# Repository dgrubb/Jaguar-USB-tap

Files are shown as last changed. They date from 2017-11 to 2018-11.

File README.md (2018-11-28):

# Jaguar USB Tap

Atari Jaguar logo

The [controller](https://atariage.com/controller_page.html?ControllerID=21&SystemID=JAGUAR) for the [Atari Jaguar](https://en.wikipedia.org/wiki/Atari_Jaguar) game console is a strange beast and doesn't map well to modern controllers (in large part due to the numeric keypad). This makes emulating games on a PC with off-the-shelf controllers, which usually mimic PlayStation or XBox layouts, somewhat cumbersome. One possible solution is to create a device which can convert the Jaguar controller's pinout and signals to a USB HID device.

## Hardware

The hardware was developed using the open-source schematic and PCB design tool [KiCad](http://kicad-pcb.org/). It sports an [STM32F070](http://www.st.com/en/microcontrollers/stm32f070cb.html) ARM Cortex M0 micro-controller which handles input from the Jaguar gamepad and generate appropriate USB HID signalling.

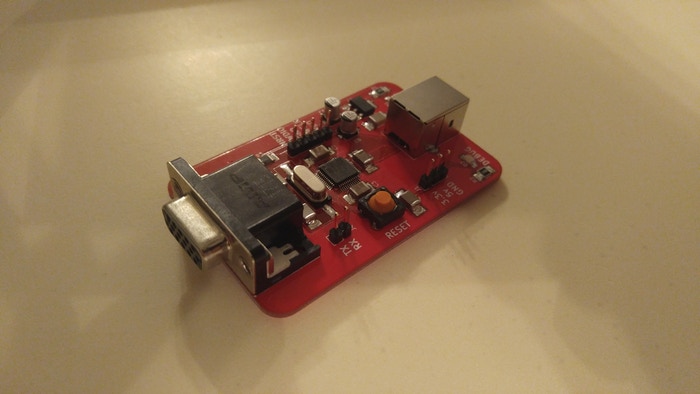
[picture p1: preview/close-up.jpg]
Assembled Jaguar USB Tap


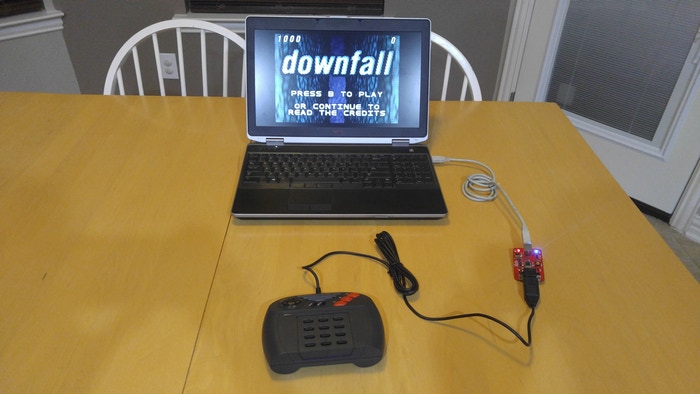
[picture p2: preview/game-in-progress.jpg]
Jaguar USB Tap


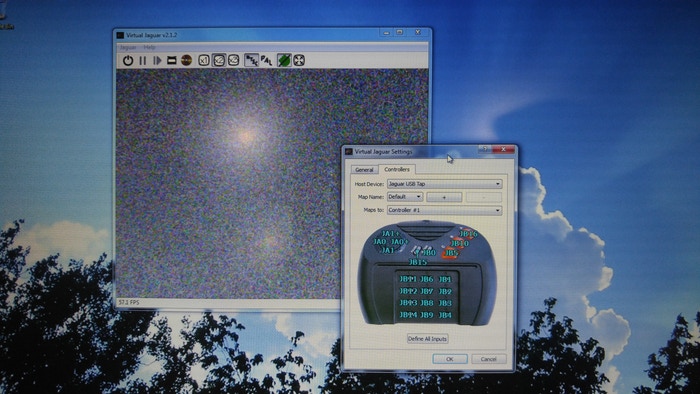
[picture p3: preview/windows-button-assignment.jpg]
Typical use case


## Accessibility

Even though the design uses entirely surface-mount (SMD) components, with the exception of connectors, I selected components with relatively large footprints such as 1812 for non-polarised capacitors. Larger components resulted in the PCB being bigger than it needs to be, but I feel this to be an acceptable trade-off to ensure that the design is accessible as they require less skill to solder and can also be identified and handled more easily by those with poorer eyesight.

At the heart of the board is an [STM32F070 microcontroller](http://www.st.com/en/microcontrollers/stm32f070cb.html). This part contains an ARM processor core, a USB peripheral and a small handful of GPIO pins making it highly suited as an embedded processor in USB human-interface devices (HID). While the part is a good technical fit for the project there are also accessibility reasons for using an STM32 uC. Chiefly, **firmware can be developed using entirely open-source tools**, such as gcc, on the user’s platform of choice (Linux, Mac OS or, I suppose, even Windows).

## Firmware

### Compatibility

I've tested on:

* Linux
* Windows 7
* MacOS X

In all cases the default USB HID driver on each system is suitable for use with the Jaguar USB Tap and enumerates correctly without additional drivers.

### Building

#### Prerequisites

Requires an ARM toolchain:

* arm-none-eabi-gcc
* arm-none-eabi-gdb
* arm-none-eabi-binutils
* OpenOCD (programming utility)

On Debian/Ubuntu: 

```
$ sudo apt-get install gcc-arm-none-eabi gdb-arm-none-eabi openocd
```
#### Make targets

To build the application:

```
$ make
```

To delete compiled objects and binaries:

```
$ make clean
```

To flash the STM32F0 over STLink:

```
$ make upload
```

To run the debugger, start an OpenOCD session with the target:

```
$ make debug
```

and then, in another terminal window:

```
$ make run_gdb
```

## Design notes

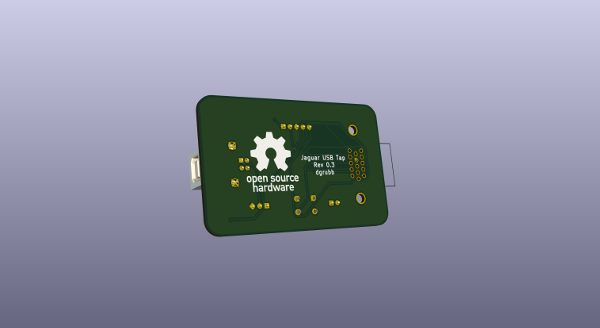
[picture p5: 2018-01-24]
preview/Jaguar-USB-tap_render_back_sm.png

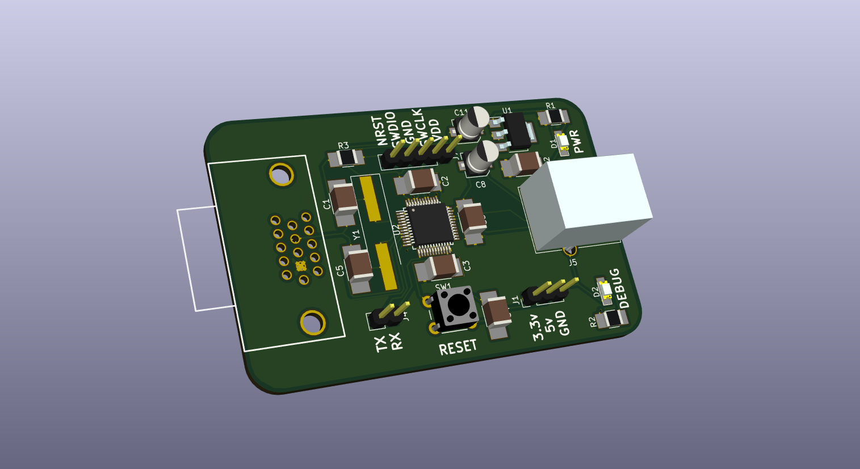
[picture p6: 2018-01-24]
preview/Jaguar-USB-tap_render.png

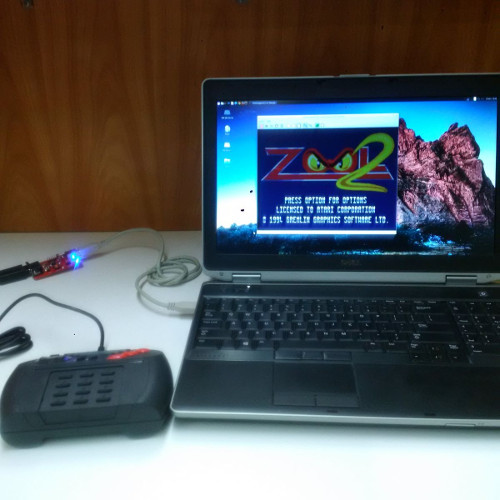
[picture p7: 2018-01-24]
preview/Jaguar-USB-Tap-in-use.jpg

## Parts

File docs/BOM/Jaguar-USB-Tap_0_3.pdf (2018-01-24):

Sheet1

Description | Name

ICs

3.3v regulator | NCP1117LPST33T3G U1
STM32F070CBT6 microcontroller | STM32F070CBT6

Connectors

3-pin header | 732-5316-ND
2-pin header | 732-5315-ND
USB-B connector | ED2983-ND
DB15 connector | 1-1734530-1
5-pin header | 732-5318-ND

Passives

RED LED (1206) | 160-1167-1-ND
BLUE LED (1206) | 160-1643-1-ND
650 Ohm resistor (1210) | P649AACT-ND
650 Ohm resistor (1210) | P649AACT-ND
10K Ohm resistor (1210) | RMCF1210FT10K0
8MHz 20pf Crystal (HC49/US) | XC1526CT-ND
20pF Capacitor (1812) | 399-7272-1-ND
0.1uF Capacitor (1812) | 399-9854-1-ND
10uF capacitor (radial can, 4.30mm x 4.30mm, 4.00mm dia) | PCE3878CT-ND

Mechanical

Push button (6mm x 6mm) | 450-1650-ND

Symbols | Quantity per | 1 Total (1)
NCP1117LPST33T3G U1 | 1 | 0.48 | $0.48
U2 | 1 | $2.52 | $2.52
J1 | 1 | $0.13 | $0.13
J4 | 1 | $0.13 | $0.13
J5 | 1 | $0.58 | $0.58
J6 | 1 | $1.98 | $1.98
J7 | 1 | $0.25 | $0.25
D1 | 1 | $0.37 | $0.37
D2 | 1 | $0.39 | $0.39
R1, R2 | 2 | $0.25 | $0.50
R1, R2 | 2 | $0.25 | $0.50
R3 | 1 | $0.16 | $0.16
Y1 | 1 | $1.12 | $1.12
C1, C5 | 2 | $1.67 | $3.34
C2, C3, C4, C6, C12 | 5 | $0.75 | $3.75
C8, C11 | 2 | $0.28 | $0.56
SW1 | 1 | $0.10 | $0.10
| | Total (1): | $16.86

10 Total (10) | 25 Total (25) | 50 Total (50) | 100
$0.40 | $0.40 | $0.40 | $0.40 | $0.40 | $0.40 | $0.27
$2.27 | $2.27 | $2.27 | $2.27 | $2.27 | $2.27 | $1.83
$0.11 | $0.11 | $0.09 | $0.09 | $0.08 | $0.08 | $0.07
$0.11 | $0.11 | $0.09 | $0.09 | $0.08 | $0.08 | $0.07
$0.55 | $0.55 | $0.50 | $0.50 | $0.44 | $0.44 | $0.42
$1.80 | $1.80 | $1.69 | $1.69 | $1.62 | $1.62 | $1.55
$0.21 | $0.21 | $0.18 | $0.18 | $0.18 | $0.18 | $0.14
$0.27 | $0.27 | $0.20 | $0.20 | $0.20 | $0.20 | $0.14
$0.28 | $0.28 | $0.24 | $0.24 | $0.24 | $0.24 | $0.19
$0.22 | $0.44 | $0.22 | $0.44 | $0.22 | $0.44 | $0.09
$0.22 | $0.44 | $0.22 | $0.44 | $0.22 | $0.44 | $0.09
$0.14 | $0.14 | $0.14 | $0.14 | $0.14 | $0.14 | $0.06
$0.99 | $0.99 | $0.99 | $0.99 | $0.93 | $0.93 | $0.82
$1.33 | $2.66 | $1.33 | $2.66 | $1.33 | $2.66 | $1.00
$0.56 | $2.80 | $0.56 | $2.80 | $0.56 | $2.80 | $0.38
$0.19 | $0.38 | $0.19 | $0.38 | $0.19 | $0.38 | $0.11
$0.10 | $0.10 | $0.09 | $0.09 | $0.09 | $0.09 | $0.08
Total (10): | $13.95 Total (25): | $13.60 Total (50): | $13.39 Total (100):

Total (100) | 250 Total (250) | 500 Total (500) | 1000 Total (1000)
$0.27 | $0.27 | $0.27 | $0.20 | $0.20 | $0.15 | $0.15
$1.83 | $1.83 | $1.83 | $1.50 | $1.50 | $1.25 | $1.25
$0.07 | $0.07 | $0.07 | $0.07 | $0.07 | $0.07 | $0.07
$0.07 | $0.07 | $0.07 | $0.07 | $0.07 | $0.07 | $0.07
$0.42 | $0.39 | $0.39 | $0.37 | $0.37 | $0.31 | $0.31
$1.55 | $1.40 | $1.40 | $1.29 | $1.29 | $1.20 | $1.20
$0.14 | $0.14 | $0.14 | $0.14 | $0.14 | $0.12 | $0.12
$0.14 | $0.10 | $0.10 | $0.09 | $0.09 | $0.07 | $0.07
$0.19 | $0.15 | $0.15 | $0.11 | $0.11 | $0.10 | $0.10
$0.18 | $0.09 | $0.18 | $0.09 | $0.18 | $0.04 | $0.08
$0.18 | $0.09 | $0.18 | $0.09 | $0.18 | $0.04 | $0.08
$0.06 | $0.06 | $0.06 | $0.06 | $0.06 | $0.03 | $0.03
$0.82 | $0.82 | $0.82 | $0.78 | $0.78 | $0.78 | $0.78
$2.00 | $1.00 | $2.00 | $0.75 | $1.50 | $0.75 | $1.50
$1.90 | $0.38 | $1.90 | $0.31 | $1.55 | $0.31 | $1.55
$0.22 | $0.11 | $0.22 | $0.08 | $0.16 | $0.07 | $0.14
$0.08 | $0.08 | $0.08 | $0.08 | $0.08 | $0.06 | $0.06
$10.12 Total (250): | $9.86 Total (500): | $8.33 Total (1000): | $7.56

Part number URL

NCP1117LPST (https://www.digikey.com/product-detail/en/on-semiconductor/NCP1117LPST33T3G/NCP1117LPST33T3GOSCT-ND/3462387)
497-15099-ND

732-5316-ND
732-5316-ND
ED2983-ND
A35116-ND
732-5318-ND

160-1167-1-N
160-1643-1-N
P649AACT-ND (https://www.digikey.com/product-detail/en/panasonic-electronic-components/ERJ-14NF6490U/P649AACT-ND/384862)
P649AACT-ND (https://www.digikey.com/product-detail/en/panasonic-electronic-components/ERJ-14NF6490U/P649AACT-ND/384862)
RMCF1210FT1 (https://www.digikey.com/product-detail/en/stackpole-electronics-inc/RMCF1210FT10K0/RMCF1210FT10K0CT-ND/1942840)
XC1526CT-ND
399-7272-1-N
399-9854-1-ND (https://www.digikey.com/product-detail/en/kemet/C1812C104KDRAC7800/399-9854-1-ND/3726199)
PCE3878CT-N

450-1650-ND

https://www.digikey.com/product-detail/en/on-semiconductor/NCP1117LPST33T3G/NCP1117LPST33T3GOSCT-ND/3462387https://www.digikey.com/product-detail/en/stmicroelectroni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

https://www.digikey.com/product-detail/en/wurth-electronics-inc/61300311121/732-5316-ND/4846825https://www.digikey.com/product-detail/en/wurth-electronics-inc/613002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

https://www.digikey.com/product-detail/en/lite-on-inc/LTST-C150CKT/160-1167-1-ND/269239https://www.digikey.com/product-detail/en/lite-on-inc/LTST-C150TBKT/160-1643-1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

https://www.digikey.com/product-detail/en/te-connectivity-alcoswitch-switches/1825910-6/450-1650-ND/1632536

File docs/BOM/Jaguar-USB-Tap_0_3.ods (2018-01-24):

Description | Name | Symbols | Quantity per board | 1 | Total (1) | 10 | Total (10) | 25 | Total (25) | 50 | Total (50) | 100 | Total (100) | 250 | Total (250) | 500 | Total (500) | 1000 | Total (1000) | Part number | URL
ICs
3.3v regulator | NCP1117LPST33T3G U1 |  | 1 | 0.48 | $0.48 | $0.40 | $0.40 | $0.40 | $0.40 | $0.40 | $0.40 | $0.27 | $0.27 | $0.27 | $0.27 | $0.20 | $0.20 | $0.15 | $0.15 | NCP1117LPST33T3GOSCT-ND | https://www.digikey.com/product-detail/en/on-semiconductor/NCP1117LPST33T3G/NCP1117LPST33T3GOSCT-ND/3462387
STM32F070CBT6 microcontroller | STM32F070CBT6 | U2 | 1 | $2.52 | $2.52 | $2.27 | $2.27 | $2.27 | $2.27 | $2.27 | $2.27 | $1.83 | $1.83 | $1.83 | $1.83 | $1.50 | $1.50 | $1.25 | $1.25 | 497-15099-ND | https://www.digikey.com/product-detail/en/stmicroelectronics/STM32F070CBT6/497-15099-ND/5051734
Connectors
3-pin header | 732-5316-ND | J1 | 1 | $0.13 | $0.13 | $0.11 | $0.11 | $0.09 | $0.09 | $0.08 | $0.08 | $0.07 | $0.07 | $0.07 | $0.07 | $0.07 | $0.07 | $0.07 | $0.07 | 732-5316-ND | https://www.digikey.com/product-detail/en/wurth-electronics-inc/61300311121/732-5316-ND/4846825
2-pin header | 732-5315-ND | J4 | 1 | $0.13 | $0.13 | $0.11 | $0.11 | $0.09 | $0.09 | $0.08 | $0.08 | $0.07 | $0.07 | $0.07 | $0.07 | $0.07 | $0.07 | $0.07 | $0.07 | 732-5316-ND | https://www.digikey.com/product-detail/en/wurth-electronics-inc/61300211121/732-5315-ND/4846823
USB-B connector | ED2983-ND | J5 | 1 | $0.58 | $0.58 | $0.55 | $0.55 | $0.50 | $0.50 | $0.44 | $0.44 | $0.42 | $0.42 | $0.39 | $0.39 | $0.37 | $0.37 | $0.31 | $0.31 | ED2983-ND | https://www.digikey.com/product-detail/en/on-shore-technology-inc/USB-B1HSB6/ED2983-ND/2677744
DB15 connector | 1-1734530-1 | J6 | 1 | $1.98 | $1.98 | $1.80 | $1.80 | $1.69 | $1.69 | $1.62 | $1.62 | $1.55 | $1.55 | $1.40 | $1.40 | $1.29 | $1.29 | $1.20 | $1.20 | A35116-ND | https://www.digikey.com/product-detail/en/te-connectivity-amp-connectors/1-1734530-1/A35116-ND/1279829
5-pin header | 732-5318-ND | J7 | 1 | $0.25 | $0.25 | $0.21 | $0.21 | $0.18 | $0.18 | $0.18 | $0.18 | $0.14 | $0.14 | $0.14 | $0.14 | $0.14 | $0.14 | $0.12 | $0.12 | 732-5318-ND | https://www.digikey.com/product-detail/en/wurth-electronics-inc/61300511121/732-5318-ND/4846831
Passives
RED LED (1206) | 160-1167-1-ND | D1 | 1 | $0.37 | $0.37 | $0.27 | $0.27 | $0.20 | $0.20 | $0.20 | $0.20 | $0.14 | $0.14 | $0.10 | $0.10 | $0.09 | $0.09 | $0.07 | $0.07 | 160-1167-1-ND | https://www.digikey.com/product-detail/en/lite-on-inc/LTST-C150CKT/160-1167-1-ND/269239
BLUE LED (1206) | 160-1643-1-ND | D2 | 1 | $0.39 | $0.39 | $0.28 | $0.28 | $0.24 | $0.24 | $0.24 | $0.24 | $0.19 | $0.19 | $0.15 | $0.15 | $0.11 | $0.11 | $0.10 | $0.10 | 160-1643-1-ND | https://www.digikey.com/product-detail/en/lite-on-inc/LTST-C150TBKT/160-1643-1-ND/573584
650 Ohm resistor (1210) | P649AACT-ND | R1, R2 | 2 | $0.25 | $0.50 | $0.22 | $0.44 | $0.22 | $0.44 | $0.22 | $0.44 | $0.09 | $0.18 | $0.09 | $0.18 | $0.09 | $0.18 | $0.04 | $0.08 | P649AACT-ND | https://www.digikey.com/product-detail/en/panasonic-electronic-components/ERJ-14NF6490U/P649AACT-ND/384862
650 Ohm resistor (1210) | P649AACT-ND | R1, R2 | 2 | $0.25 | $0.50 | $0.22 | $0.44 | $0.22 | $0.44 | $0.22 | $0.44 | $0.09 | $0.18 | $0.09 | $0.18 | $0.09 | $0.18 | $0.04 | $0.08 | P649AACT-ND | https://www.digikey.com/product-detail/en/panasonic-electronic-components/ERJ-14NF6490U/P649AACT-ND/384862
10K Ohm resistor (1210) | RMCF1210FT10K0 | R3 | 1 | $0.16 | $0.16 | $0.14 | $0.14 | $0.14 | $0.14 | $0.14 | $0.14 | $0.06 | $0.06 | $0.06 | $0.06 | $0.06 | $0.06 | $0.03 | $0.03 | RMCF1210FT10K0CT-ND | https://www.digikey.com/product-detail/en/stackpole-electronics-inc/RMCF1210FT10K0/RMCF1210FT10K0CT-ND/1942840
8MHz 20pf Crystal (HC49/US) | XC1526CT-ND | Y1 | 1 | $1.12 | $1.12 | $0.99 | $0.99 | $0.99 | $0.99 | $0.93 | $0.93 | $0.82 | $0.82 | $0.82 | $0.82 | $0.78 | $0.78 | $0.78 | $0.78 | XC1526CT-ND | https://www.digikey.com/product-detail/en/ecs-inc/ECS-80-20-5PXDU-TR/XC1526CT-ND/1693695
20pF Capacitor (1812) | 399-7272-1-ND | C1, C5 | 2 | $1.67 | $3.34 | $1.33 | $2.66 | $1.33 | $2.66 | $1.33 | $2.66 | $1.00 | $2.00 | $1.00 | $2.00 | $0.75 | $1.50 | $0.75 | $1.50 | 399-7272-1-ND | https://www.digikey.com/product-detail/en/kemet/C1812C200JCGACTU/399-7272-1-ND/3439465
0.1uF Capacitor (1812) | 399-9854-1-ND | C2, C3, C4, C6, C12 | 5 | $0.75 | $3.75 | $0.56 | $2.80 | $0.56 | $2.80 | $0.56 | $2.80 | $0.38 | $1.90 | $0.38 | $1.90 | $0.31 | $1.55 | $0.31 | $1.55 | 399-9854-1-ND | https://www.digikey.com/product-detail/en/kemet/C1812C104KDRAC7800/399-9854-1-ND/3726199
10uF capacitor (radial can, 4.30mm x 4.30mm, 4.00mm dia) | PCE3878CT-ND | C8, C11 | 2 | $0.28 | $0.56 | $0.19 | $0.38 | $0.19 | $0.38 | $0.19 | $0.38 | $0.11 | $0.22 | $0.11 | $0.22 | $0.08 | $0.16 | $0.07 | $0.14 | PCE3878CT-ND | https://www.digikey.com/product-detail/en/panasonic-electronic-components/EEE-1CA100SR/PCE3878CT-ND/766254
Mechanical
Push button (6mm x 6mm) | 450-1650-ND | SW1 | 1 | $0.10 | $0.10 | $0.10 | $0.10 | $0.09 | $0.09 | $0.09 | $0.09 | $0.08 | $0.08 | $0.08 | $0.08 | $0.08 | $0.08 | $0.06 | $0.06 | 450-1650-ND | https://www.digikey.com/product-detail/en/te-connectivity-alcoswitch-switches/1825910-6/450-1650-ND/1632536
 |  |  |  | Total (1): | $16.86 | Total (10): | $13.95 | Total (25): | $13.60 | Total (50): | $13.39 | Total (100): | $10.12 | Total (250): | $9.86 | Total (500): | $8.33 | Total (1000): | $7.56

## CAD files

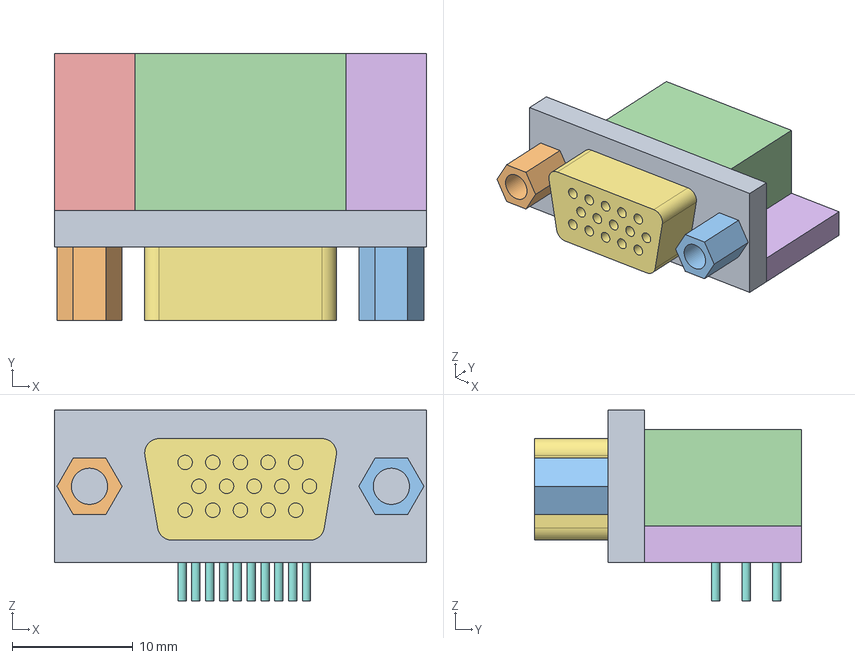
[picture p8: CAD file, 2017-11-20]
Hardware/DB15-SPC15430/conn_SPC15430.fcstd
30.8 x 22.1 x 15.8 mm
Front
Fix2
Fix1
BoxRear
RearFix2
RearFix003
Pins

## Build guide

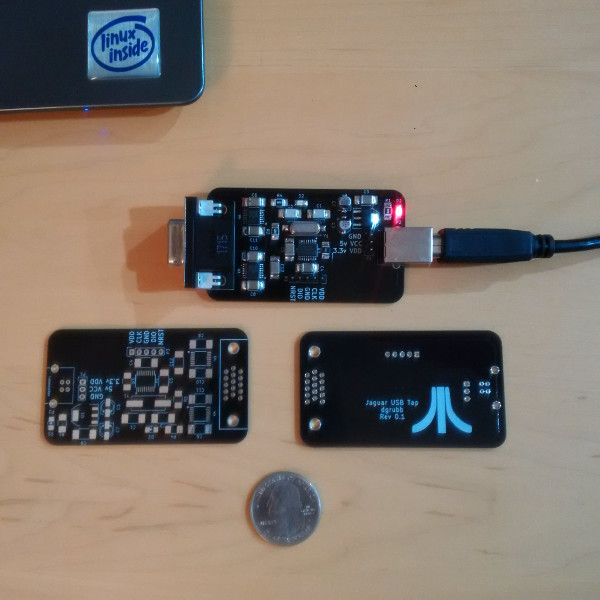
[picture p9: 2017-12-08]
preview/Jaguar-USB-Tap-assembled.jpg

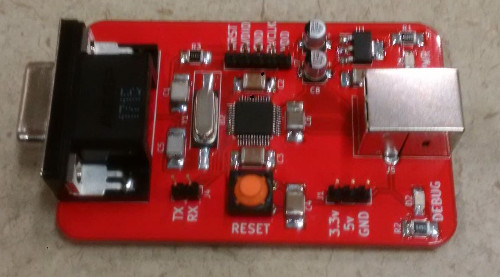
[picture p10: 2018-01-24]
preview/Jaguar-USB-Tap_0_3_assembled.jpg

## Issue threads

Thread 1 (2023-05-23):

Axis locking when diagonals are pressed on D-Pad

BitJag, 2023-05-23:
I've been using this device on and off for the years that I have had it.  I have noticed in the last year or so that when I press diagonally in any direction it will sometimes lock one of the axes.  As if it it is still being pressed.  Taping any button on the controller seems to break the lock.  It seems like my device didn't have this problem at least when I first had it.

I have tested this in linux (Kubuntu 22.04, wine window 7 compatibility) and windows 11 through the Bigpemu with the same results.  I also tried multiple Jaguar controllers with the same effect.  I have tested this in both Bigpemu and with a few games on steam with the same effect.  It seems to be a problem with the device.

I decided to post an issue here in case this might be a bug that has cropped up overtime.  I doubt this is the problem because this happens in both Windows and Linux and the chances of some driver or method for handling HID changing in both ecosystems causing the same problem is unlikely.

With very little information available for a niche device, this is my last attempt at least diagnosing if there is a problem with the device, or discovering some sort of software adjustment I need to make in my OS/application that I have overlooked.

Here is a desktop recording of the problem.  It's a bit hard to notice without using the controller yourself, but anytime it seems like the character is turning for no good reason is when the axis locks up from me pressing diagonally.

https://youtu.be/6YMD81gCsRc

Let me know if there is anything else I can do on my end that might help discover the problem.

Thanks for any help you can give.

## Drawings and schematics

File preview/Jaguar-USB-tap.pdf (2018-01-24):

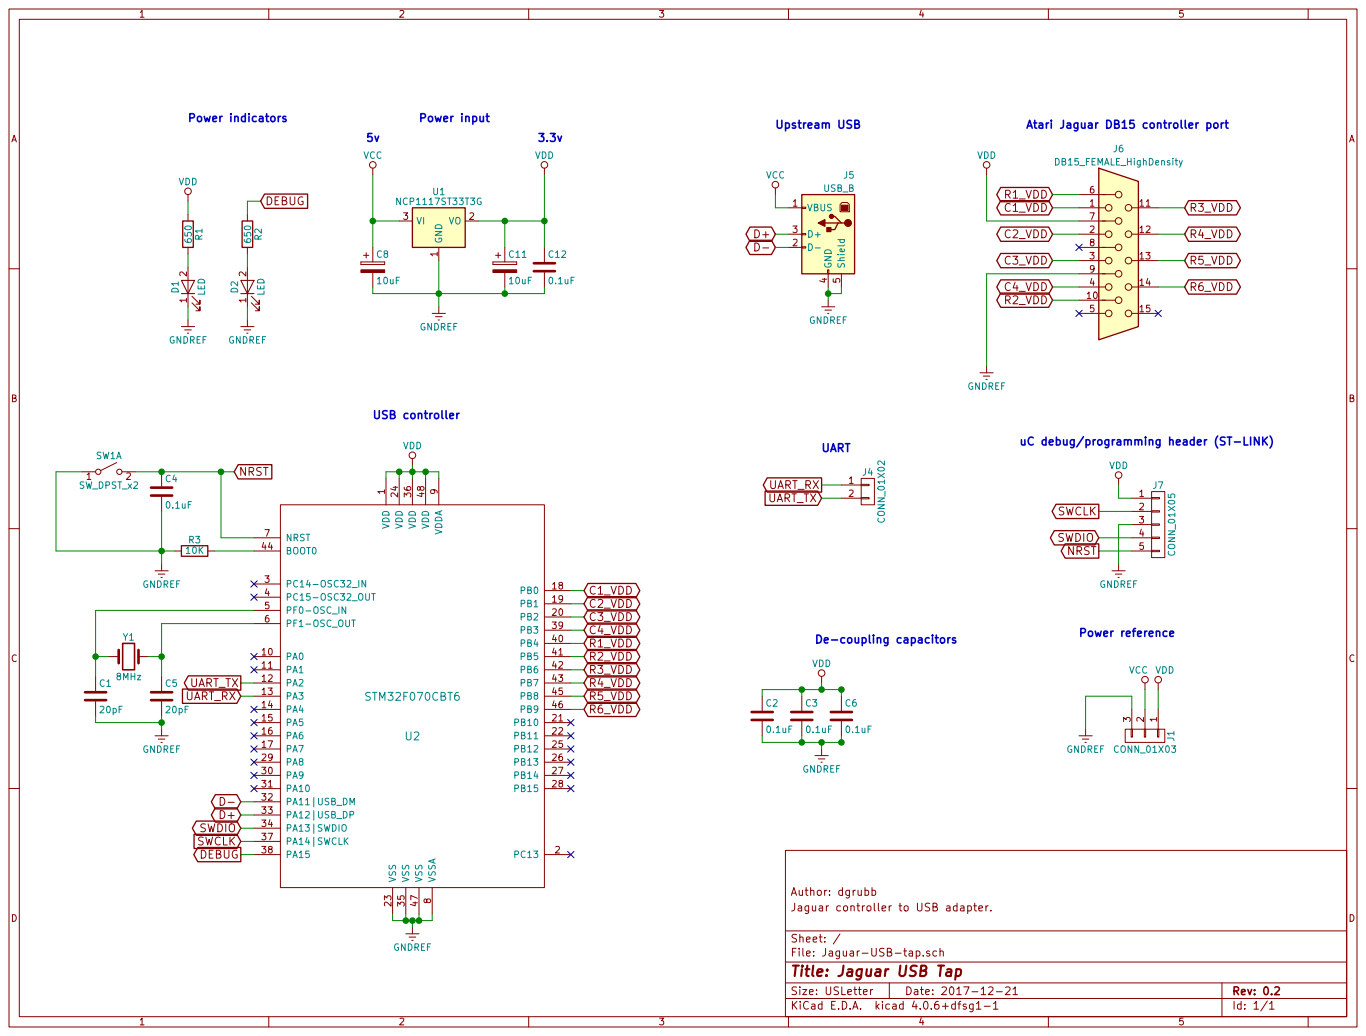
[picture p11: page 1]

VDD GNDREF GNDREF VCC DEBUG

uC debug/programming header (ST-LINK) UART De-coupling capacitors
1/2 J4 CONN_01X02

File: Jaguar-USB-tap.sch Sheet: / Jaguar controller to USB adapter.

Id: 1/1 Title: Jaguar USB Tap

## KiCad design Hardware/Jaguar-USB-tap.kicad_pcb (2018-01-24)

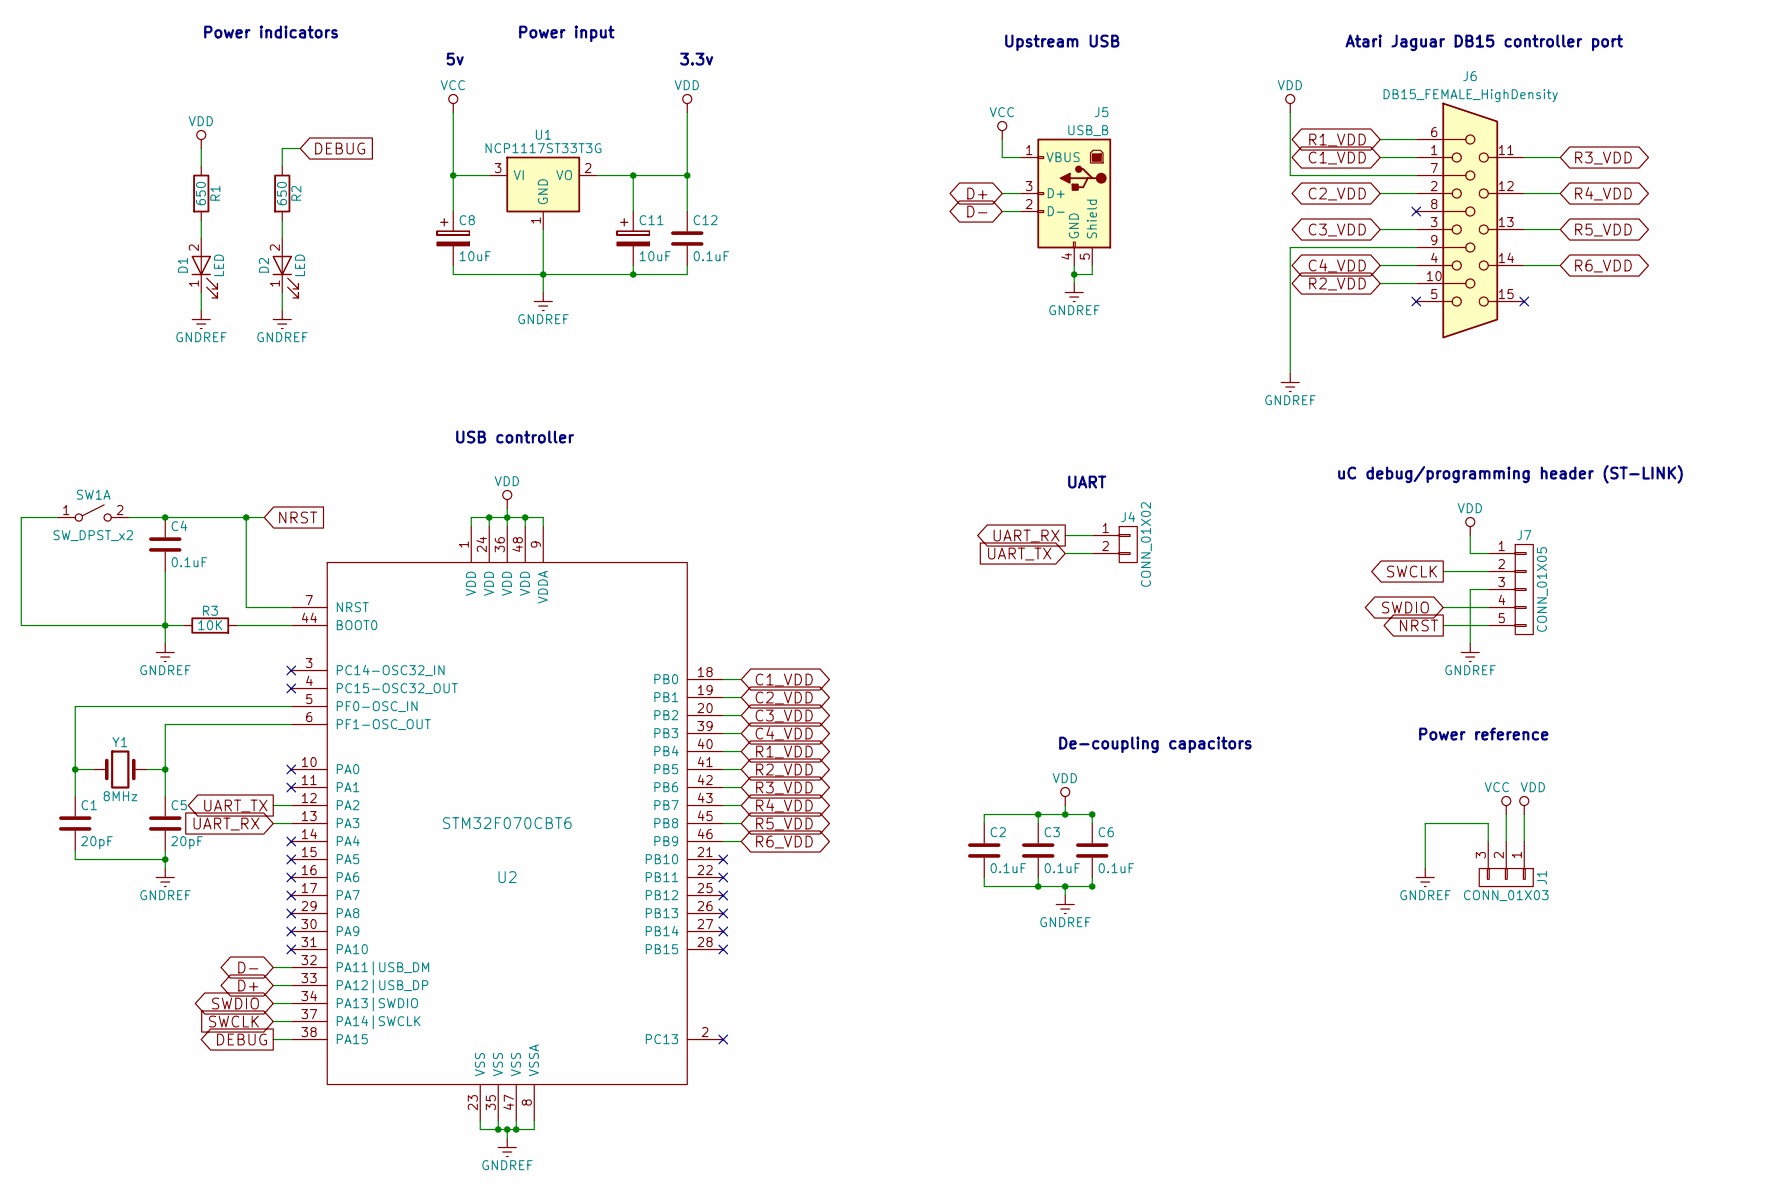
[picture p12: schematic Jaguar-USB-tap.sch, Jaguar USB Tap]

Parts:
C1, C5: 20pF; C_1812_HandSoldering
C2, C3, C4, C6, C12: 0.1uF; C_1812_HandSoldering
C8, C11: 10uF; CP_Elec_4x5.8
D1, D2: LED; LED_1206
J1: CONN_01X03; Pin_Header_Straight_1x03_Pitch2.54mm
J4: CONN_01X02; Pin_Header_Straight_1x02_Pitch2.54mm
J5: USB_B
J6: DB15_FEMALE_HighDensity; conn_SPC15430
J7: CONN_01X05; Pin_Header_Straight_1x05_Pitch2.54mm
R1, R2: 650; R_1210_HandSoldering
R3: 10K; R_1210_HandSoldering
SW1: SW_DPST_x2; SW_PUSH_6mm
U1: NCP1117ST33T3G; SOT-223
U2: STM32F070CBT6; LQFP-48_7x7mm_Pitch0.5mm
Y1: 8MHz; Crystal_SMD_HC49-SD_HandSoldering

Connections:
C1_VDD: J6.1, U2.18 (PB0)
C2_VDD: J6.2, U2.19 (PB1)
C3_VDD: J6.3, U2.20 (PB2)
C4_VDD: J6.4, U2.39 (PB3)
D+: J5.3 (D+), U2.33 (PA12|USB_DP)
D-: J5.2 (D-), U2.32 (PA11|USB_DM)
DEBUG: R2.1, U2.38 (PA15)
GNDREF: C1.2, C2.2, C3.2, C4.2, C5.2, C6.2, C8.2, C11.2, C12.2, D1.1 (K), D2.1 (K), J1.3, J5.4 (GND), J5.5 (Shield), J6.9, J7.3, R3.1, SW1.1 (A), U1.1 (GND), U2.8 (VSSA), U2.23 (VSS), U2.35 (VSS), U2.47 (VSS)
NRST: C4.1, J7.5, SW1.2 (B), U2.7 (NRST)
unnamed: C1.1, U2.5 (PF0-OSC_IN), Y1.1
unnamed: C5.1, U2.6 (PF1-OSC_OUT), Y1.2
unnamed: D1.2 (A), R1.2
unnamed: D2.2 (A), R2.2
unnamed: R3.2, U2.44 (BOOT0)
R1_VDD: J6.6, U2.40 (PB4)
R2_VDD: J6.10, U2.41 (PB5)
R3_VDD: J6.11, U2.42 (PB6)
R4_VDD: J6.12, U2.43 (PB7)
R5_VDD: J6.13, U2.45 (PB8)
R6_VDD: J6.14, U2.46 (PB9)
SWCLK: J7.2, U2.37 (PA14|SWCLK)
SWDIO: J7.4, U2.34 (PA13|SWDIO)
UART_RX: J4.1, U2.13 (PA3)
UART_TX: J4.2, U2.12 (PA2)
VCC: C8.1, J1.2, J5.1 (VBUS), U1.3 (VI)
VDD: C2.1, C3.1, C6.1, C11.1, C12.1, J1.1, J6.7, J7.1, R1.1, U1.2 (VO), U2.1 (VDD), U2.9 (VDDA), U2.24 (VDD), U2.36 (VDD), U2.48 (VDD)

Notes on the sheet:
Power indicators
Power input
3.3v
Power reference
Upstream USB
Atari Jaguar DB15 controller port
uC debug/programming header (ST-LINK)
UART
De-coupling capacitors
USB controller

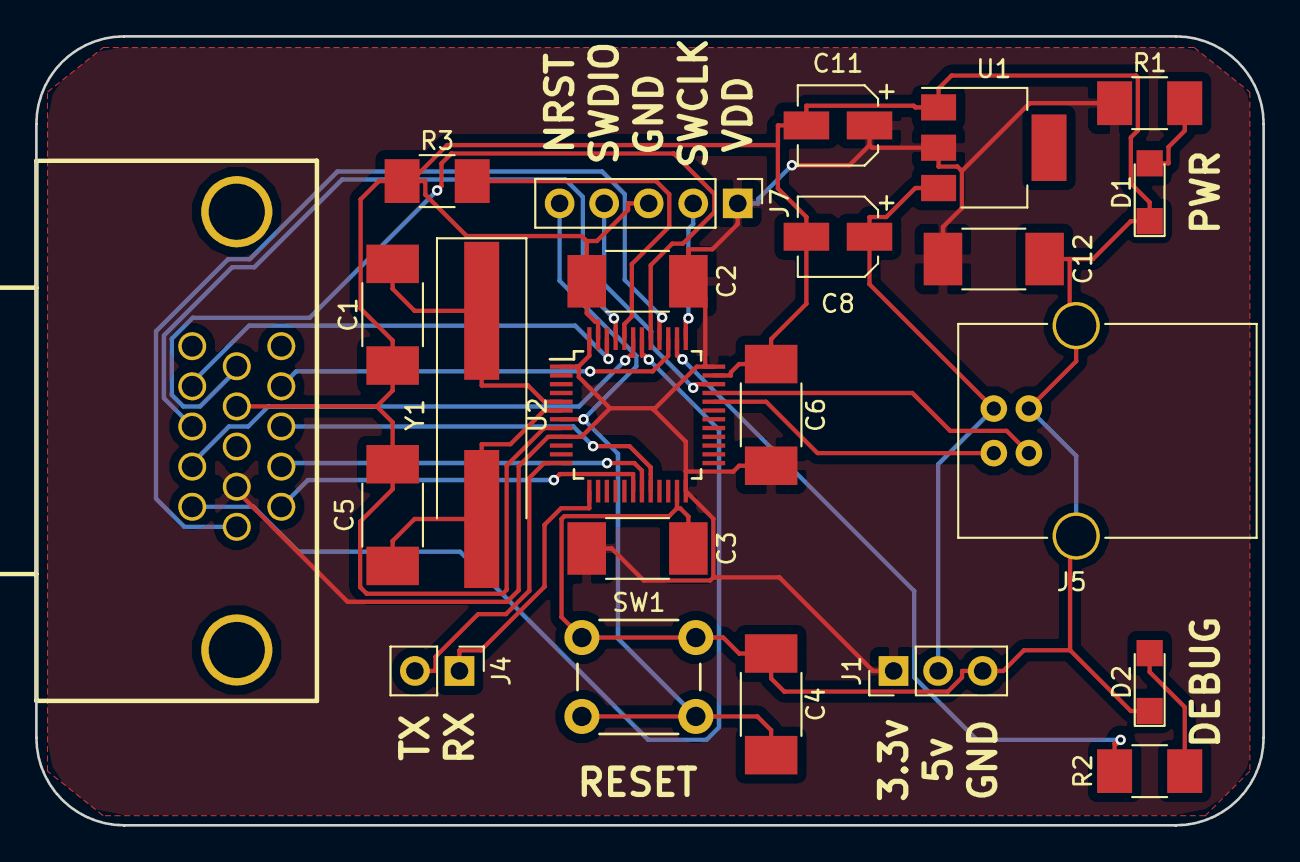
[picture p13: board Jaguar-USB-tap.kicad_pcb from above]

Board: 2 copper layers, 70.0 x 45.0 mm, 23 parts (0 on the bottom side), 26 nets.

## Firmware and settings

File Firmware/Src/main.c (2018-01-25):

#include <string.h>
#include "main.h"
#include "stm32f0xx_hal.h"
#include "usb_device.h"
#include "jaguar/jaguar-controller.h"

static char welcome_message[] = "\n\r"
"\n\r"
"            Jaguar-USB-tap\n\r"
"            --------------\n\r"
"\n\r"
"         by David Grubb, 2018\n\r"
"  https://github.com/dgrubb/Jaguar-USB-tap\n\r"
"\n\r"
"A USB adapter for the Atari Jaguar controller.\n\r"
"\n\r"
"            Welcome to 1993!\n\r";

UART_HandleTypeDef huart2;

void SystemClock_Config(void);
static void MX_GPIO_Init(void);
static void MX_USART2_UART_Init(void);

int main(void)
{
    /* Reset of all peripherals, Initializes the Flash interface and the Systick. */
    HAL_Init();

    /* Configure the system clock */
    SystemClock_Config();

    /* Initialize all configured peripherals */
    MX_GPIO_Init();
    MX_USART2_UART_Init();
    MX_USB_DEVICE_Init();

    /* Turn on the DEBUG LED for visual indication that we're up and running and
     * display a welcome message on the UART 
     * */
    HAL_GPIO_WritePin(GPIOA, GPIO_PIN_15, GPIO_PIN_SET);
    HAL_UART_Transmit(&huart2, (uint8_t *)welcome_message, strlen(welcome_message), HAL_MAX_DELAY);

    /* Infinite loop */
    while (1) {
        jaguar_update_inputs(&huart2);
    }
}

void systick_init()
{
    (void) SysTick_Config (HAL_RCC_GetSysClockFreq()/1000);
}

void SystemClock_Config(void)
{
    RCC_OscInitTypeDef RCC_OscInitStruct;
    RCC_ClkInitTypeDef RCC_ClkInitStruct;
    RCC_PeriphCLKInitTypeDef PeriphClkInit;

    /* Use the external 8MHz crystal (HSE) and multiply it
     * by 6 for a resulting core frequency of 48MHz.
     */
    RCC_OscInitStruct.OscillatorType = RCC_OSCILLATORTYPE_HSE;
    RCC_OscInitStruct.HSEState = RCC_HSE_ON;
    RCC_OscInitStruct.PLL.PLLState = RCC_PLL_ON;
    RCC_OscInitStruct.PLL.PLLSource = RCC_PLLSOURCE_HSE;
    RCC_OscInitStruct.PLL.PLLMUL = RCC_PLL_MUL6;
    RCC_OscInitStruct.PLL.PREDIV = RCC_PREDIV_DIV1;
    if (HAL_RCC_OscConfig(&RCC_OscInitStruct) != HAL_OK) {
        _Error_Handler(__FILE__, __LINE__);
    }

    RCC_ClkInitStruct.ClockType = RCC_CLOCKTYPE_HCLK   |
                                  RCC_CLOCKTYPE_SYSCLK |
                                  RCC_CLOCKTYPE_PCLK1;
    RCC_ClkInitStruct.SYSCLKSource = RCC_SYSCLKSOURCE_PLLCLK;
    RCC_ClkInitStruct.AHBCLKDivider = RCC_SYSCLK_DIV1;
    RCC_ClkInitStruct.APB1CLKDivider = RCC_HCLK_DIV1;

    if (HAL_RCC_ClockConfig(&RCC_ClkInitStruct, FLASH_LATENCY_1) != HAL_OK) {
        _Error_Handler(__FILE__, __LINE__);
    }

    /* Enable the USB clock and drive it from the multiplied external
     * oscillator. The external crystal is necessary for consistency at high-speeds,
     * otherwise drift will cause oddities on the USB clock rate.
     */
    PeriphClkInit.PeriphClockSelection = RCC_PERIPHCLK_USB;
    PeriphClkInit.UsbClockSelection = RCC_USBCLKSOURCE_PLL;

    if (HAL_RCCEx_PeriphCLKConfig(&PeriphClkInit) != HAL_OK) {
        _Error_Handler(__FILE__, __LINE__);
    }

    HAL_SYSTICK_Config(HAL_RCC_GetHCLKFreq()/1000);
    HAL_SYSTICK_CLKSourceConfig(SYSTICK_CLKSOURCE_HCLK);
    HAL_NVIC_SetPriority(SysTick_IRQn, 0, 0);
}

static void MX_USART2_UART_Init(void)
{
    /*
     * TX: Pin PA2
     * RX: Pin PA3
     *
     * UART settings (PuTTY, Minicom etc):
     *
     * Baud: 152000
     * Data len: 8 bits
     * Stop bit: 1
     * No hardware control.
     */
    huart2.Instance = USART2;
    huart2.Init.BaudRate = 115200;
    huart2.Init.WordLength = UART_WORDLENGTH_8B;
    huart2.Init.StopBits = UART_STOPBITS_1;
    huart2.Init.Parity = UART_PARITY_NONE;
    huart2.Init.Mode = UART_MODE_TX_RX;
    huart2.Init.HwFlowCtl = UART_HWCONTROL_NONE;
    huart2.Init.OverSampling = UART_OVERSAMPLING_16;
    huart2.Init.OneBitSampling = UART_ONE_BIT_SAMPLE_DISABLE;
    huart2.AdvancedInit.AdvFeatureInit = UART_ADVFEATURE_NO_INIT;
    if (HAL_UART_Init(&huart2) != HAL_OK) {
        _Error_Handler(__FILE__, __LINE__);
    }
}

static void MX_GPIO_Init(void)
{
    GPIO_InitTypeDef GPIO_InitStruct;

    /* GPIO Ports Clock Enable */
    __HAL_RCC_GPIOF_CLK_ENABLE();
    __HAL_RCC_GPIOA_CLK_ENABLE();
    __HAL_RCC_GPIOB_CLK_ENABLE();

    /*Configure GPIO pin Output Level */
    HAL_GPIO_WritePin(GPIOA, GPIO_PIN_15, GPIO_PIN_RESET);

    /* Pins PB0 through PB3 are used as ouputs for setting the 
     * address lines of the Jaguar controller.
     */
    GPIO_InitStruct.Pin = GPIO_PIN_0 | GPIO_PIN_1 | GPIO_PIN_2 | GPIO_PIN_3;
    GPIO_InitStruct.Mode = GPIO_MODE_OUTPUT_PP;
    GPIO_InitStruct.Pull = GPIO_PULLUP;
    GPIO_InitStruct.Speed = GPIO_SPEED_FREQ_LOW;
    HAL_GPIO_Init(GPIOB, &GPIO_InitStruct);

    /* Pins PB4 through PB9 are set as inputs for reading the
     * button states of those buttons assigned to the selected address.
     */
    GPIO_InitStruct.Pin = GPIO_PIN_4 | GPIO_PIN_5 | GPIO_PIN_6 |
                          GPIO_PIN_7 | GPIO_PIN_8 | GPIO_PIN_9;
    GPIO_InitStruct.Mode = GPIO_MODE_INPUT;
    GPIO_InitStruct.Pull = GPIO_NOPULL;
    HAL_GPIO_Init(GPIOB, &GPIO_InitStruct);

    /* Setup pin PA15, connected to the LED labelled DEBUG on the silkscreen, as
     * an output.
     */
    GPIO_InitStruct.Pin = GPIO_PIN_15;
    GPIO_InitStruct.Mode = GPIO_MODE_OUTPUT_PP;
    GPIO_InitStruct.Pull = GPIO_NOPULL;
    GPIO_InitStruct.Speed = GPIO_SPEED_FREQ_LOW;
    HAL_GPIO_Init(GPIOA, &GPIO_InitStruct);
}

void _Error_Handler(char * file, int line)
{
    while(1) {}
}

#ifdef USE_FULL_ASSERT

void assert_failed(uint8_t* file, uint32_t line)
{
}

#endif

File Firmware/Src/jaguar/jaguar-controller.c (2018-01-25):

/*
 * File: jaguar-controller.c
 * Author: dgrubb
 * Date: 30/11/2017
 *
 * Interpret digital I/O in context of Jaguar controller.
 */

#include <string.h>
#include "usb_device.h"
#include "jaguar-controller.h"

static GPIO_TypeDef *jaguar_port = GPIOB;

uint8_t jaguar_usb_data[JAGUAR_USB_REPORT_LENGTH];

static jaguar_button_info_t jaguar_button_mapping[] = {
    /* Column 1 */
    { JAGUAR_BUTTON_OPTION, JAGUAR_DB15_PIN1, JAGUAR_DB15_PIN10, JAGUAR_BUTTON_STATE_UP, JAGUAR_USB_BUTTON_OPTION },
    { JAGUAR_BUTTON_THREE,  JAGUAR_DB15_PIN1, JAGUAR_DB15_PIN11, JAGUAR_BUTTON_STATE_UP, JAGUAR_USB_BUTTON_THREE },
    { JAGUAR_BUTTON_SIX,    JAGUAR_DB15_PIN1, JAGUAR_DB15_PIN12, JAGUAR_BUTTON_STATE_UP, JAGUAR_USB_BUTTON_SIX },
    { JAGUAR_BUTTON_NINE,   JAGUAR_DB15_PIN1, JAGUAR_DB15_PIN13, JAGUAR_BUTTON_STATE_UP, JAGUAR_USB_BUTTON_NINE },
    { JAGUAR_BUTTON_POUND,  JAGUAR_DB15_PIN1, JAGUAR_DB15_PIN14, JAGUAR_BUTTON_STATE_UP, JAGUAR_USB_BUTTON_POUND },
    /* Column 2 */
    { JAGUAR_BUTTON_C,      JAGUAR_DB15_PIN2, JAGUAR_DB15_PIN10, JAGUAR_BUTTON_STATE_UP, JAGUAR_USB_BUTTON_C },
    { JAGUAR_BUTTON_TWO,    JAGUAR_DB15_PIN2, JAGUAR_DB15_PIN11, JAGUAR_BUTTON_STATE_UP, JAGUAR_USB_BUTTON_TWO },
    { JAGUAR_BUTTON_FIVE,   JAGUAR_DB15_PIN2, JAGUAR_DB15_PIN12, JAGUAR_BUTTON_STATE_UP, JAGUAR_USB_BUTTON_FIVE },
    { JAGUAR_BUTTON_EIGHT,  JAGUAR_DB15_PIN2, JAGUAR_DB15_PIN13, JAGUAR_BUTTON_STATE_UP, JAGUAR_USB_BUTTON_EIGHT },
    { JAGUAR_BUTTON_ZERO,   JAGUAR_DB15_PIN2, JAGUAR_DB15_PIN14, JAGUAR_BUTTON_STATE_UP, JAGUAR_USB_BUTTON_ZERO },
    /* Column 3 */
    { JAGUAR_BUTTON_B,      JAGUAR_DB15_PIN3, JAGUAR_DB15_PIN10, JAGUAR_BUTTON_STATE_UP, JAGUAR_USB_BUTTON_B },
    { JAGUAR_BUTTON_ONE,    JAGUAR_DB15_PIN3, JAGUAR_DB15_PIN11, JAGUAR_BUTTON_STATE_UP, JAGUAR_USB_BUTTON_ONE },
    { JAGUAR_BUTTON_FOUR,   JAGUAR_DB15_PIN3, JAGUAR_DB15_PIN12, JAGUAR_BUTTON_STATE_UP, JAGUAR_USB_BUTTON_FOUR },
    { JAGUAR_BUTTON_SEVEN,  JAGUAR_DB15_PIN3, JAGUAR_DB15_PIN13, JAGUAR_BUTTON_STATE_UP, JAGUAR_USB_BUTTON_SEVEN },
    { JAGUAR_BUTTON_STAR,   JAGUAR_DB15_PIN3, JAGUAR_DB15_PIN14, JAGUAR_BUTTON_STATE_UP, JAGUAR_USB_BUTTON_STAR },
    /* Column 4 */
    { JAGUAR_BUTTON_PAUSE,  JAGUAR_DB15_PIN4, JAGUAR_DB15_PIN6,  JAGUAR_BUTTON_STATE_UP, JAGUAR_USB_BUTTON_PAUSE },
    { JAGUAR_BUTTON_A,      JAGUAR_DB15_PIN4, JAGUAR_DB15_PIN10, JAGUAR_BUTTON_STATE_UP, JAGUAR_USB_BUTTON_A },
    { JAGUAR_BUTTON_EAST,   JAGUAR_DB15_PIN4, JAGUAR_DB15_PIN11, JAGUAR_BUTTON_STATE_UP, JAGUAR_USB_BUTTON_NONE },
    { JAGUAR_BUTTON_WEST,   JAGUAR_DB15_PIN4, JAGUAR_DB15_PIN12, JAGUAR_BUTTON_STATE_UP, JAGUAR_USB_BUTTON_NONE },
    { JAGUAR_BUTTON_SOUTH,  JAGUAR_DB15_PIN4, JAGUAR_DB15_PIN13, JAGUAR_BUTTON_STATE_UP, JAGUAR_USB_BUTTON_NONE },
    { JAGUAR_BUTTON_NORTH,  JAGUAR_DB15_PIN4, JAGUAR_DB15_PIN14, JAGUAR_BUTTON_STATE_UP, JAGUAR_USB_BUTTON_NONE }
};

void jaguar_update_inputs(UART_HandleTypeDef *uart)
{
    char debug_msg[JAGUAR_DEBUG_MSG_LENGTH];
    jaguar_db15_pin_t address_pin = JAGUAR_DB15_PIN_UNKNOWN;
    uint32_t i=0;
    jaguar_button_state_t button_state;

    for (i=0; i<JAGUAR_BUTTON_LENGTH; i++) {
        if (address_pin != jaguar_button_mapping[i].address_pin) {
            /* Only switch the address pins if a new address is required. Buttons
             * are ordered in the button mapping table so that addresses are
             * grouped together and should only need switching four times for a 
             * complete sweep of all the buttons.
             * */
            jaguar_select_address(jaguar_button_mapping[i].address_pin);
        }
        /* N.B: data pins are active low (RESET) when pressed.
         */
        if (GPIO_PIN_RESET == HAL_GPIO_ReadPin(jaguar_port, jaguar_button_mapping[i].row_pin)) {
            button_state = JAGUAR_BUTTON_STATE_DOWN;
        } else {
            button_state = JAGUAR_BUTTON_STATE_UP;
        }
        /* Update the new button state and send messages on UART (for debug)
         * and USB (for fun).
         */
        if (button_state != jaguar_button_mapping[i].state) {
            jaguar_button_mapping[i].state = button_state;
            memset(debug_msg, 0, JAGUAR_DEBUG_MSG_LENGTH);
            sprintf(
                debug_msg,
                "Button: %s - %s\n\r",
                jaguar_get_button_str(jaguar_button_mapping[i].button),
                jaguar_get_button_state_str(jaguar_button_mapping[i].state)
            );
            jaguar_send_USB_report();
            HAL_UART_Transmit(uart, (uint8_t *)debug_msg, JAGUAR_DEBUG_MSG_LENGTH, HAL_MAX_DELAY);
        }
    }
}

void jaguar_select_address(jaguar_db15_pin_t address_pin)
{
    /* Reset all address pins */
    HAL_GPIO_WritePin(GPIOB, GPIO_PIN_0, GPIO_PIN_SET);
    HAL_GPIO_WritePin(GPIOB, GPIO_PIN_1, GPIO_PIN_SET);
    HAL_GPIO_WritePin(GPIOB, GPIO_PIN_2, GPIO_PIN_SET);
    HAL_GPIO_WritePin(GPIOB, GPIO_PIN_3, GPIO_PIN_SET);
    /* Now enable our desired address line */
    HAL_GPIO_WritePin(GPIOB, address_pin, GPIO_PIN_RESET);
}

void jaguar_send_USB_report()
{
    jaguar_usb_report_t report;
    uint8_t i = 0;
    memset(&report, 0, sizeof(jaguar_usb_report_t));
    memset(&jaguar_usb_data, 0, JAGUAR_USB_REPORT_LENGTH);

    /* Scan the keymap to build a complete report of current button state */
    while (jaguar_button_mapping[i].button != JAGUAR_BUTTON_EAST) {
        if (jaguar_button_mapping[i].state == JAGUAR_BUTTON_STATE_DOWN) {
            report.buttons |= jaguar_button_mapping[i].usb_mask;
        } else {
            report.buttons &= ~jaguar_button_mapping[i].usb_mask;
        }
        /* Check the next button in sequence*/
        i++;
    }

    /* Handle D-pad as a special case */
    if (jaguar_button_mapping[JAGUAR_BUTTON_NORTH].state == JAGUAR_BUTTON_STATE_DOWN) report.y = 127;
    if (jaguar_button_mapping[JAGUAR_BUTTON_SOUTH].state == JAGUAR_BUTTON_STATE_DOWN) report.y = -127;
    if (jaguar_button_mapping[JAGUAR_BUTTON_EAST].state == JAGUAR_BUTTON_STATE_DOWN) report.x = 127;
    if (jaguar_button_mapping[JAGUAR_BUTTON_WEST].state == JAGUAR_BUTTON_STATE_DOWN) report.x = -127;

    /* Package report data into a flat array */
    jaguar_usb_data[0] = (uint8_t)report.buttons;
    jaguar_usb_data[1] = (uint8_t)(report.buttons >> 8);
    jaguar_usb_data[2] = (uint8_t)(report.buttons >> 16);
    jaguar_usb_data[3] = report.x;
    jaguar_usb_data[4] = report.y;

    MX_USB_DEVICE_Send(jaguar_usb_data, JAGUAR_USB_REPORT_LENGTH);
}

const char* jaguar_get_button_state_str(jaguar_button_state_t state)
{
    switch (state) {
        case JAGUAR_BUTTON_STATE_UP:   return "Up";
        case JAGUAR_BUTTON_STATE_DOWN: return "Down";
        default:                       return "Unknown";
    }
}
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

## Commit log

2017-11-20 Add skeleton of project structure.
    [Jaguar-USB-tap.kicad_pcb, Jaguar-USB-tap.sch]
2017-11-20 Add a new part library to include our chosen uC device (STM32F070F6P6).
2017-11-20 Progress on hardware piece.
    1) Add documenation for TI logic level shifter.
    2) Finish up initial schematic.
    3) Add clear .pdf before adding component footprints.
    4) Add libraries for TI logic level shifter.
    [Jaguar-USB-tap.sch, conn_SPC15430.fcstd]
2017-11-20 Add a preview image for casual inspection.
    [Jaguar-USB-tap.sch]
2017-11-20 Add PCB work.
    1) Add footprints for TSSOP16 and TSSOP20 devices.
    2) Create a PCB layout for adapter and board cut.
    [Jaguar-USB-tap.kicad_pcb, Jaguar-USB-tap.sch]
2017-11-20 Add a preview of the board itself.
2017-11-20 Add traces and fill zones to PCB.
    [Jaguar-USB-tap.dsn, Jaguar-USB-tap.kicad_pcb]
2017-11-20 Add Gerbers for producing boards.
    [Jaguar-USB-tap-B.Cu.gbr, Jaguar-USB-tap-B.Mask.gbr, Jaguar-USB-tap-B.SilkS.gbr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]
2017-11-20 Add a BOM spreadsheet with pricing from DigiKey.
2017-11-20 Move BOM into its own directory and export a pdf for convenience.
    [Jaguar-USB-tap-BOM.ods]
2017-11-21 Add a smaller version of the rendered board.
2017-11-21 Add ST and ARM components (CMSIS and HAl drivers).
2017-11-21 Circuit improvements.
    1) Add an indicator LED to OE.
    2) Add a capacitor to NRST.
    [Jaguar-USB-tap.kicad_pcb, Jaguar-USB-tap.sch]
2017-11-21 Minor tweaks for PCB layout positioning of components.
    [Jaguar-USB-tap.kicad_pcb]
2017-11-21 Update Gerbers and drill files to reflect tweaks to schematic.
    [Jaguar-USB-tap-B.Cu.gbr, Jaguar-USB-tap-B.Mask.gbr, Jaguar-USB-tap-B.SilkS.gbr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]
2017-11-21 Add ST USB device library.
2017-11-28 Update silkscreen artwork.
    [Jaguar-USB-tap.kicad_pcb]
2017-11-28 Add updated gerber files.
    [Jaguar-USB-tap-B.Cu.gbr, Jaguar-USB-tap-B.Mask.gbr, Jaguar-USB-tap-B.SilkS.gbr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]
2017-11-30 Add some function prototypes to Jaguar controller.
2017-12-01 Add a button mapping type to identify what address/data pins belong to which controller buttons.
2017-12-01 Add a pin mapping between the DB15 socket and the uCs PA port.
2017-12-01 Enable pin PB1 for output.
2017-12-02 Fix pointer references to GPIO port.
    [jaguar-controller.c]
2017-12-05 Turn on a test pin on bootup (this is tied to an LED).
2017-12-08 Add image of an assembled board and blank PCBs.
2017-12-08 Change OpenOCD configuration to explicitly target our ST-LINK and STM32F07 parts, rather than relying on a Nucleo wrapper.
2017-12-12 Dramatic change of tact: remove hand-rolled handlers and startup definitions in favour of those generated by STM32CubeMX.
2017-12-21 Rework schematic to fx hardware bugs and add features.
    1) Add jumpers for OE to allow manual disabling of logic-level translator ICs.
    2) Add RESET button.
    3) Upgrade to larger STM32F07 series IC so ST-LINK SWD lines don't have to pull double-duty as general-purpose GPIO. Allows for continued debugging during operation.
    4) Fix missing pin assignments in previous board which prevented proper powerng of uC.
    [Jaguar-USB-tap-B.Cu.gbr, Jaguar-USB-tap-B.Mask.gbr, Jaguar-USB-tap-B.SilkS.gbr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]
2017-12-21 Start PCB layout of revised board.
    [Jaguar-USB-tap.kicad_pcb, Jaguar-USB-tap.sch]
2017-12-22 Finish up PCB layout with traces and zone pours.
    [Jaguar-USB-tap.dsn, Jaguar-USB-tap.kicad_pcb]
2018-01-04 Switch target uC from STM32F070RB to STM32F070CBT6.
    [Jaguar-USB-tap-B.Cu.gbr, Jaguar-USB-tap-B.Mask.gbr, Jaguar-USB-tap-B.SilkS.gbr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]
2018-01-05 Re-allocate button mapping according to pin mapping for 0.2 rev board.
2018-01-05 Progress due to testing with actual hardware.
    1) Enable some basic serial debugging.
    2) Rewrite pin reading functions according to gained knowledge about how the controller addresses buttons.
2018-01-10 Remove logic-level translation ICs and drive teh controller at 3.3v directly from the uC.
    [Jaguar-USB-tap-B.Cu.gbr, Jaguar-USB-tap-B.Mask.gbr, Jaguar-USB-tap-B.SilkS.gbr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]
2018-01-19 Add an ASCII art based welcome message to UART on startup.
2018-01-22 Ensure we have enough bits to send all button states.
2018-01-24 Remove old BOMs.
    [Jaguar-USB-tap-BOM.ods]
2018-01-24 Add updated BOM.
    [Jaguar-USB-Tap_0_3.ods]
2018-01-24 Remove Atari branding and replace with OSHW logo instead.
    [Jaguar-USB-tap-B.Cu.gbr, Jaguar-USB-tap-B.Mask.gbr, Jaguar-USB-tap-B.SilkS.gbr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]
2018-01-24 Add new pictures of revised board.
2018-01-24 Remove old schematics.
2018-01-24 Add PDF schematic.
2018-01-24 Cast string before sending over UART to silence compiler warning.
2018-01-24 Ensure correct pointer type when dispatching USB message.
    [jaguar-controller.c]
2018-01-25 Add a shiny new VID/PID, courtesy of pid.codes
2018-01-25 Switch debug flag off and remove an out-dated comment.
2018-01-30 Correct VID/PID pair by changing to base-16 in code.
